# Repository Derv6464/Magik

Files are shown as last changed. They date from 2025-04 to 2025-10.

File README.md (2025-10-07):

# Magik - Flight Computer

This was built as a final year project for college, as well as to create a flight computer for ULAS HiPR.
The code and pcb are rough drafts with work to be done before the first flight. 

## Hardware
The code & pcb were created with a rp2040 chip in mind

## Report
Full report can be veiwed in the repo

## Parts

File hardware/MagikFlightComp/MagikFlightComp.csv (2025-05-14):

Comment | Designator | Footprint | LCSC
Antenna | AE1
Antenna | AE2 | Connector_Coaxial:SMA_Molex_73251-1153_EdgeMount_Horizontal
Buzzer | BZ1 | Buzzer_Beeper:Buzzer_12x9.5RM7.6
100nF | C1,C2,C3,C4,C6 | Capacitor_SMD:C_0603_1608Metric_Pad1.08x0.95mm_HandSolder
1uF | C10,C11 | Capacitor_SMD:C_0603_1608Metric_Pad1.08x0.95mm_HandSolder
10uF | C5 | Capacitor_SMD:C_0603_1608Metric_Pad1.08x0.95mm_HandSolder
47pF | C7 | Capacitor_SMD:C_0603_1608Metric_Pad1.08x0.95mm_HandSolder
22uF | C8,C9 | Capacitor_SMD:C_0603_1608Metric_Pad1.08x0.95mm_HandSolder
LED | D1 | LED_SMD:LED_1210_3225Metric
WS2812B | D2 | LED_SMD:LED_WS2812B_PLCC4_5.0x5.0mm_P3.2mm
2601-1104 | J1,J3 | CONN4_2601-1104_WAG
Debug Socket | J2
Conn_01x03_Socket | J4 | Connector_JST:JST_PH_B3B-PH-K_1x03_P2.00mm_Vertical
Conn_01x02_Pin | J5 | Connector_PinHeader_1.00mm:PinHeader_1x02_P1.00mm_Vertical
6.8uH | L1 | Inductor_SMD:L_0603_1608Metric_Pad1.05x0.95mm_HandSolder
NDT3055L | Q1,Q2 | Package_TO_SOT_SMD:SOT-223-3_TabPin2
1k | R1 | Resistor_SMD:R_0603_1608Metric_Pad0.98x0.95mm_HandSolder
10k | R2,R3 | Resistor_SMD:R_0603_1608Metric_Pad0.98x0.95mm_HandSolder
158k | R4 | Resistor_SMD:R_0603_1608Metric_Pad0.98x0.95mm_HandSolder
30.1k | R5 | Resistor_SMD:R_0603_1608Metric_Pad0.98x0.95mm_HandSolder
Pico | U1 | Module_RaspberryPi_Pico:RaspberryPi_Pico_W_SMD_HandSolder
Ai-Thinker-Ra-01 | U2 | RF_Module:Ai-Thinker-Ra-01-LoRa
MAX-M10S | U3 | RF_GPS:ublox_MAX
ADXL375BCCZ-RL7 | U4 | LGA_CC-14-1_ADI
LSM6DSO32TR | U5 | LSM6D032:LGA-14L_2P5X3X0P83_STM
MS560702BA03-50 | U6 | MS5607:SON8_MS5611_TEC
AP63300WU-7 | U7 | TSOT6_AP63300WU-7_DIO

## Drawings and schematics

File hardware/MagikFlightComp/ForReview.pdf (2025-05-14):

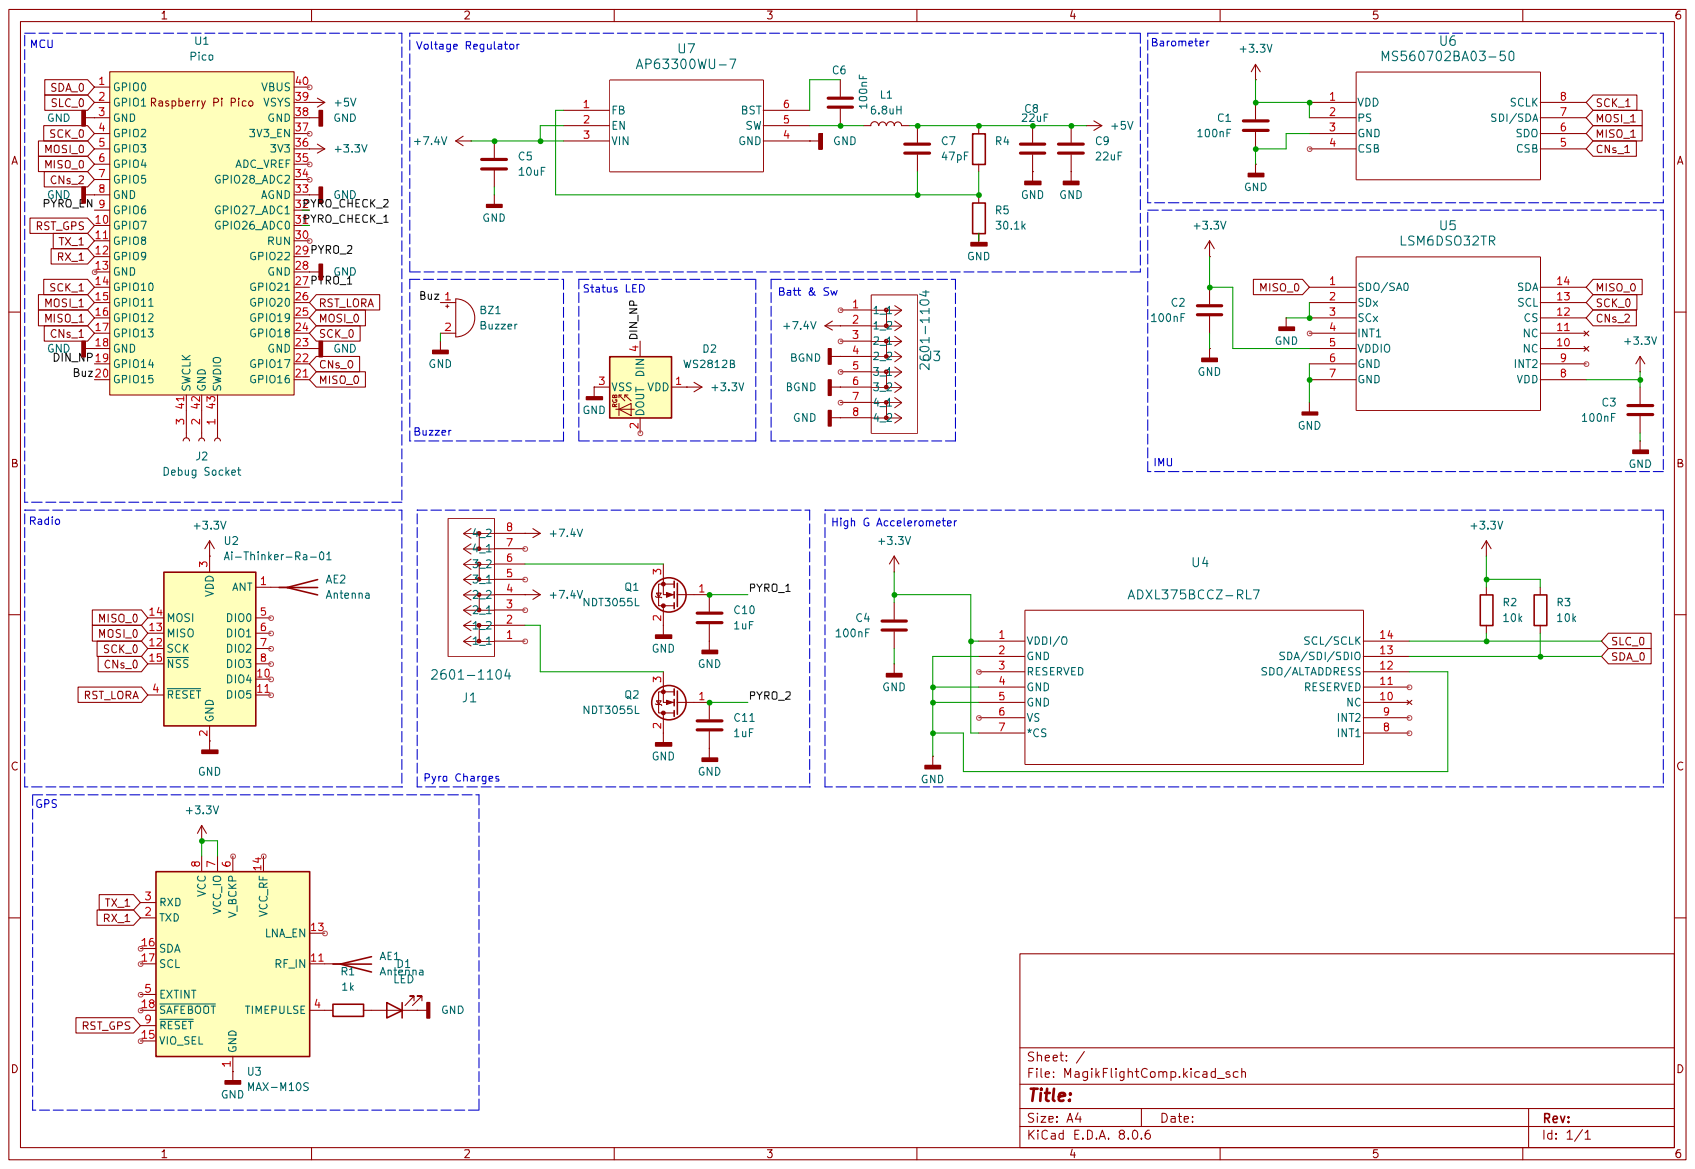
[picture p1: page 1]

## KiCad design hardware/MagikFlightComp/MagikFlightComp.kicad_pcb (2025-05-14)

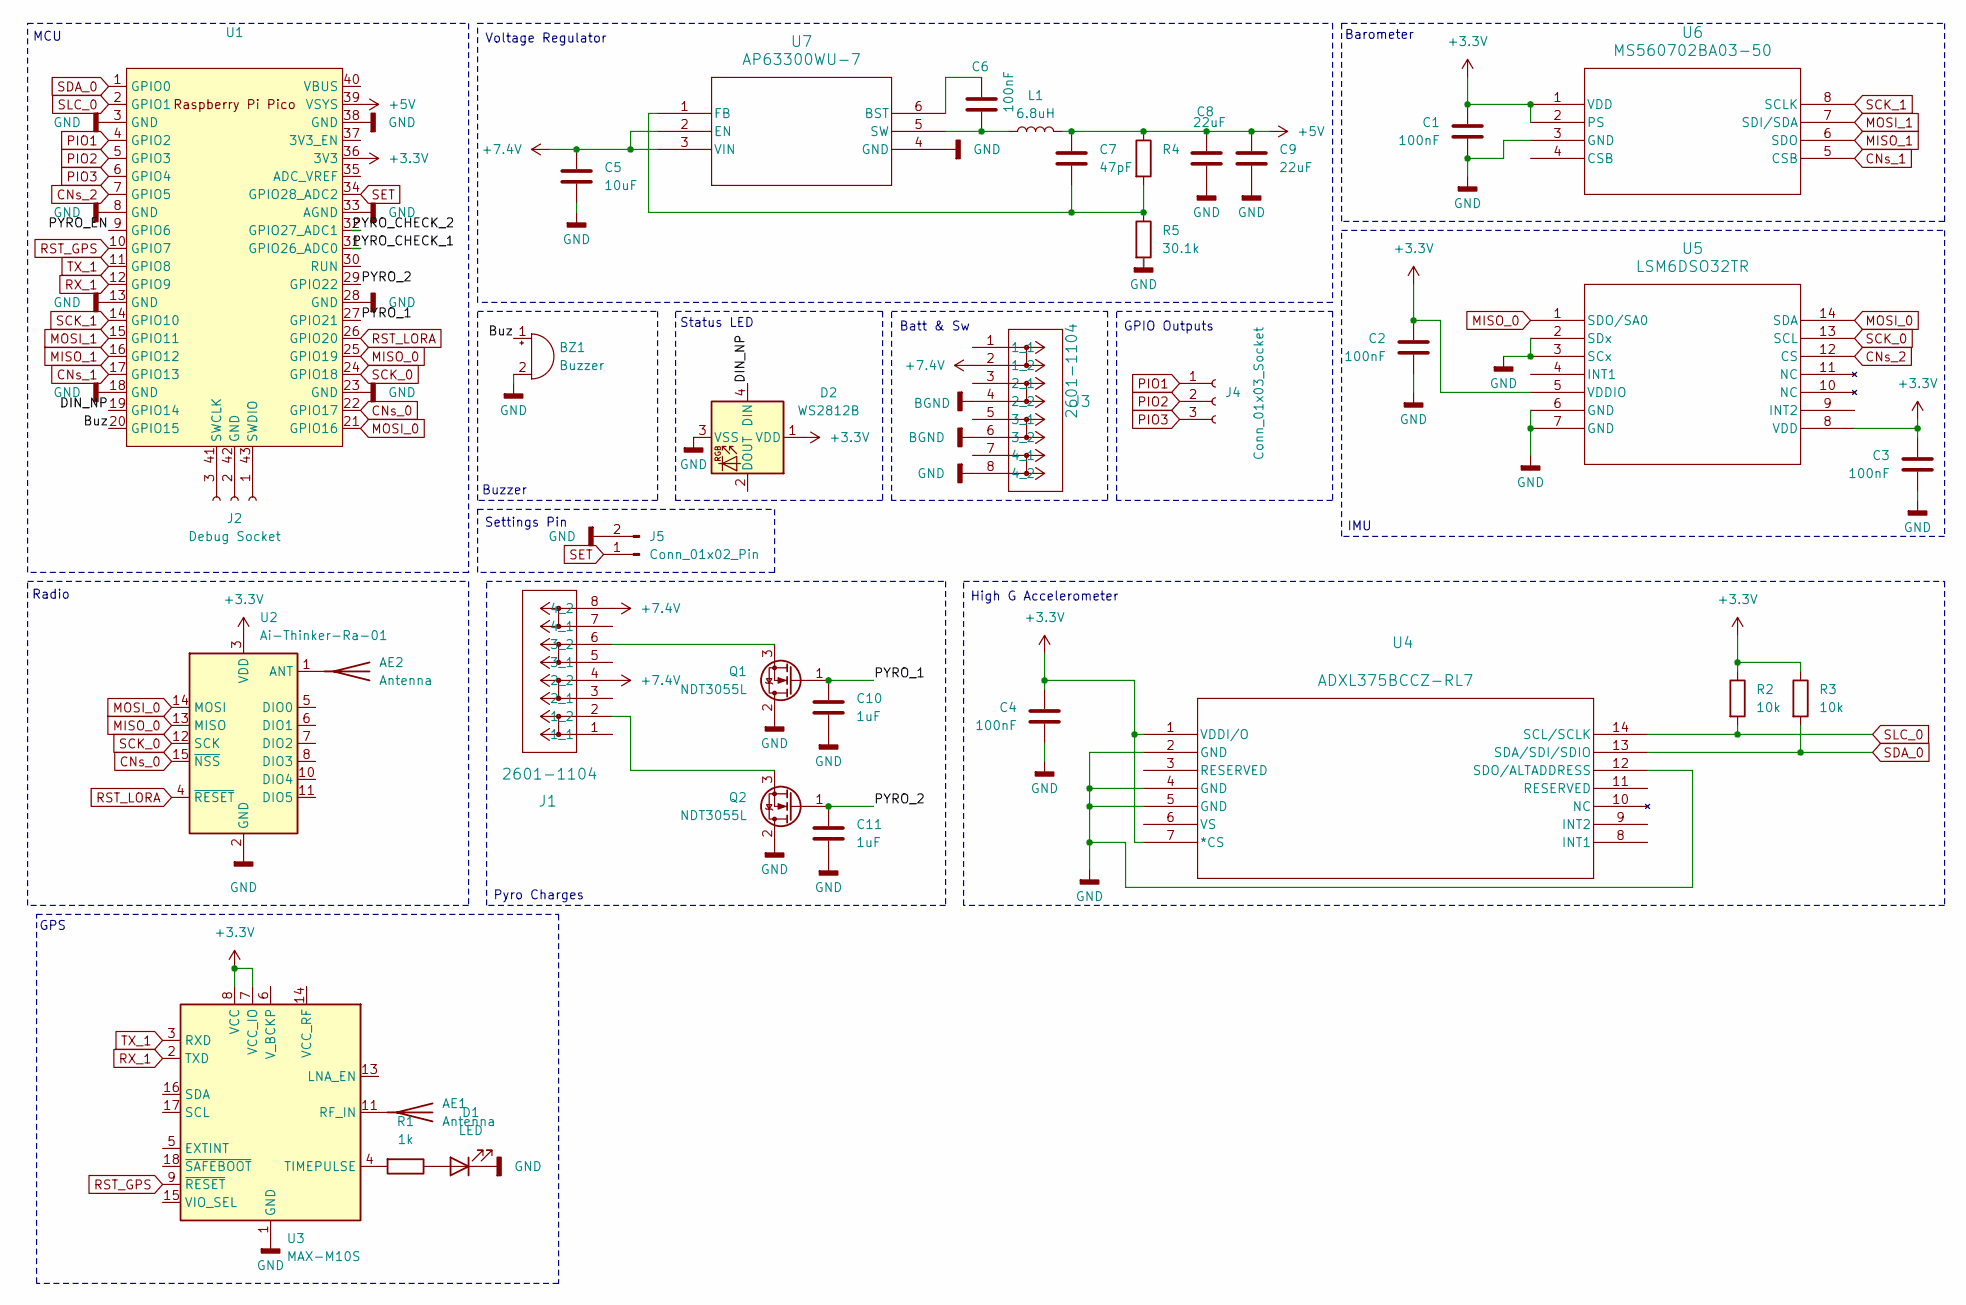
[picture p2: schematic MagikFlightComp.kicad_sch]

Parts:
AE1: Antenna
AE2: Antenna; SMA_Molex_73251-1153_EdgeMount_Horizontal
BZ1: Buzzer; Buzzer_12x9.5RM7.6
C1, C2, C3, C4, C6: 100nF; C_0603_1608Metric_Pad1.08x0.95mm_HandSolder
C5: 10uF; C_0603_1608Metric_Pad1.08x0.95mm_HandSolder
C7: 47pF; C_0603_1608Metric_Pad1.08x0.95mm_HandSolder
C8, C9: 22uF; C_0603_1608Metric_Pad1.08x0.95mm_HandSolder
C10, C11: 1uF; C_0603_1608Metric_Pad1.08x0.95mm_HandSolder
D1: LED; LED_1210_3225Metric
D2: WS2812B; LED_WS2812B_PLCC4_5.0x5.0mm_P3.2mm
J1, J3: 2601-1104; CONN4_2601-1104_WAG
J2: Debug Socket
J4: Conn_01x03_Socket; JST_PH_B3B-PH-K_1x03_P2.00mm_Vertical
J5: Conn_01x02_Pin; PinHeader_1x02_P1.00mm_Vertical
L1: 6.8uH; L_0603_1608Metric_Pad1.05x0.95mm_HandSolder
Q1, Q2: NDT3055L; SOT-223-3_TabPin2
R1: 1k; R_0603_1608Metric_Pad0.98x0.95mm_HandSolder
R2, R3: 10k; R_0603_1608Metric_Pad0.98x0.95mm_HandSolder
R4: 158k; R_0603_1608Metric_Pad0.98x0.95mm_HandSolder
R5: 30.1k; R_0603_1608Metric_Pad0.98x0.95mm_HandSolder
U1: Pico; RaspberryPi_Pico_W_SMD_HandSolder
U2: Ai-Thinker-Ra-01; Ai-Thinker-Ra-01-LoRa
U3: MAX-M10S; ublox_MAX
U4: ADXL375BCCZ-RL7; LGA_CC-14-1_ADI
U5: LSM6DSO32TR; LGA-14L_2P5X3X0P83_STM
U6: MS560702BA03-50; SON8_MS5611_TEC
U7: AP63300WU-7; TSOT6_AP63300WU-7_DIO

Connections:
+3.3V: C1.1, C2.1, C3.1, C4.1, D2.1 (VDD), R2.1, R3.1, U1.36 (3V3), U2.3 (VDD), U3.7 (VCC_IO), U3.8 (VCC), U4.1 (VDDI/O), U4.7 (*CS), U5.5 (VDDIO), U5.8 (VDD), U6.1 (VDD), U6.2 (PS)
+5V: C7.1, C8.1, C9.1, L1.2, R4.1, U1.39 (VSYS)
+7.4V: C5.1, J1.4 (2_2), J1.8 (4_2), J3.2 (1_2), U7.2 (EN), U7.3 (VIN)
/Buz: BZ1.1 (+), U1.20 (GPIO15)
/DIN_NP: D2.4 (DIN), U1.19 (GPIO14)
/PYRO_1: C10.1, Q1.1 (G), U1.27 (GPIO21)
/PYRO_2: C11.1, Q2.1 (G), U1.29 (GPIO22)
/PYRO_CHECK_1: U1.31 (GPIO26_ADC0)
/PYRO_CHECK_2: U1.32 (GPIO27_ADC1)
/PYRO_EN: U1.9 (GPIO6)
BGND: J3.4 (2_2), J3.6 (3_2)
CNs_0: U1.22 (GPIO17), U2.15 (~NSS)
CNs_1: U1.17 (GPIO13), U6.5 (CSB)
CNs_2: U1.7 (GPIO5), U5.12 (CS)
GND: BZ1.2 (-), C1.2, C2.2, C3.2, C4.2, C5.2, C8.2, C9.2, C10.2, C11.2, D1.1 (K), D2.3 (VSS), J3.8 (4_2), J5.2, Q1.2 (D), Q2.2 (D), R5.2, U1.3 (GND), U1.8 (GND), U1.13 (GND), U1.18 (GND), U1.23 (GND), U1.28 (GND), U1.33 (AGND), U1.38 (GND), U2.2 (GND), U2.9 (GND), U2.16 (GND), U3.1 (GND), U3.10 (GND), U3.12 (GND), U4.2 (GND), U4.4 (GND), U4.5 (GND), U4.12 (SDO/ALTADDRESS), U5.2 (SDx), U5.3 (SCx), U5.6 (GND), U5.7 (GND), U6.3 (GND), U7.4 (GND)
MISO_0: U1.25 (GPIO19), U2.13 (MISO), U5.1 (SDO/SA0)
MISO_1: U1.16 (GPIO12), U6.6 (SDO)
MOSI_0: U1.21 (GPIO16), U2.14 (MOSI), U5.14 (SDA)
MOSI_1: U1.15 (GPIO11), U6.7 (SDI/SDA)
unnamed: AE1.1, U3.11 (RF_IN)
unnamed: AE2.1 (A), U2.1 (ANT)
unnamed: D1.2 (A), R1.1
unnamed: J1.2 (1_2), Q2.3 (S)
unnamed: J1.6 (3_2), Q1.3 (S)
unnamed: J2.1, U1.43 (SWDIO)
unnamed: J2.2, U1.42 (GND)
unnamed: J2.3, U1.41 (SWCLK)
unnamed: R1.2, U3.4 (TIMEPULSE)
unnamed: C6.1, U7.6 (BST)
unnamed: C7.2, R4.2, R5.1, U7.1 (FB)
unnamed: C6.2, L1.1, U7.5 (SW)
PIO1: J4.1, U1.4 (GPIO2)
PIO2: J4.2, U1.5 (GPIO3)
PIO3: J4.3, U1.6 (GPIO4)
RST_GPS: U1.10 (GPIO7), U3.9 (~RESET)
RST_LORA: U1.26 (GPIO20), U2.4 (~RESET)
RX_1: U1.12 (GPIO9), U3.2 (TXD)
SCK_0: U1.24 (GPIO18), U2.12 (SCK), U5.13 (SCL)
SCK_1: U1.14 (GPIO10), U6.8 (SCLK)
SDA_0: R3.2, U1.1 (GPIO0), U4.13 (SDA/SDI/SDIO)
SET: J5.1, U1.34 (GPIO28_ADC2)
SLC_0: R2.2, U1.2 (GPIO1), U4.14 (SCL/SCLK)
TX_1: U1.11 (GPIO8), U3.3 (RXD)

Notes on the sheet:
Radio
Buzzer
Settings Pin
High G Accelerometer
Voltage Regulator
GPS
MCU
Status LED
IMU
Batt & Sw
GPIO Outputs
Pyro Charges
Barometer

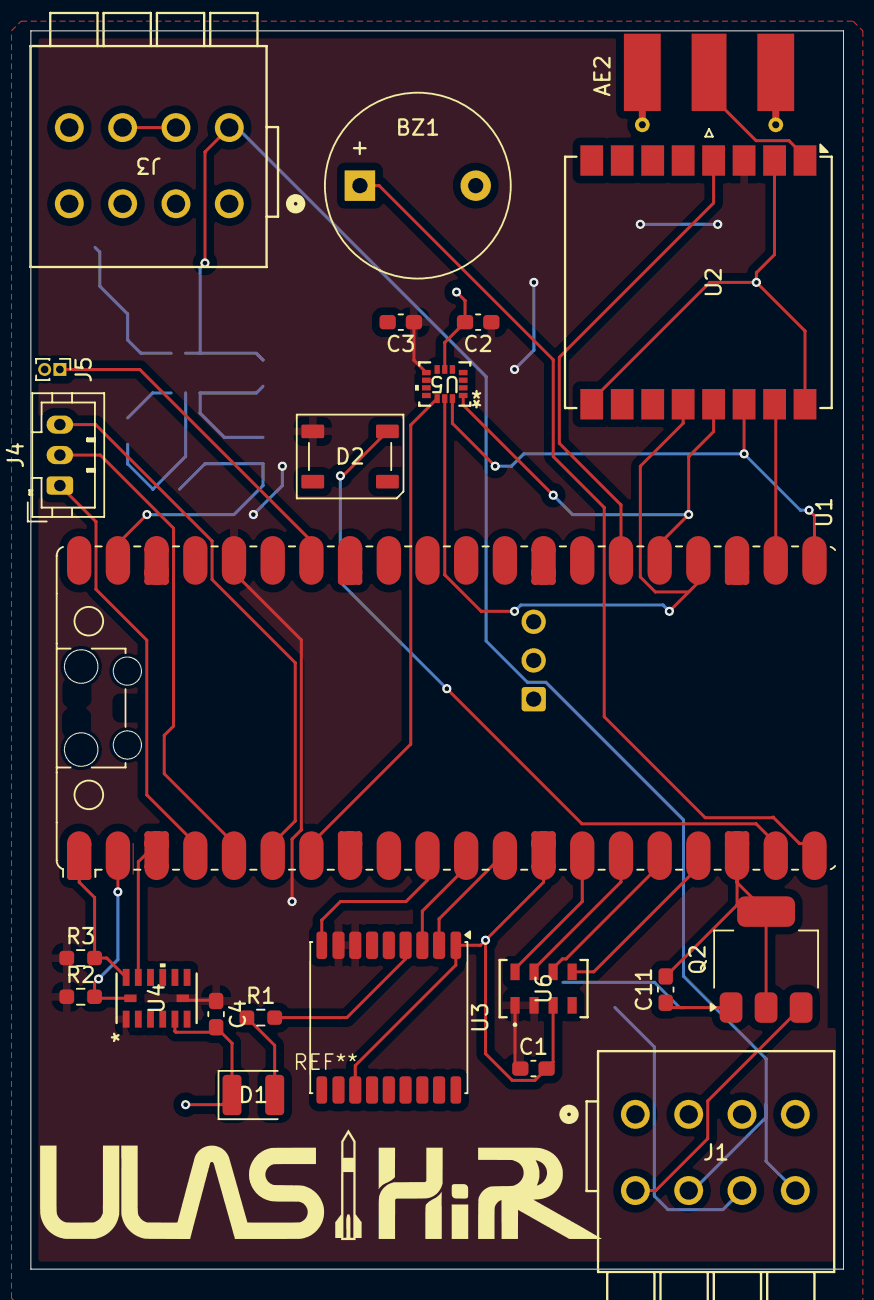
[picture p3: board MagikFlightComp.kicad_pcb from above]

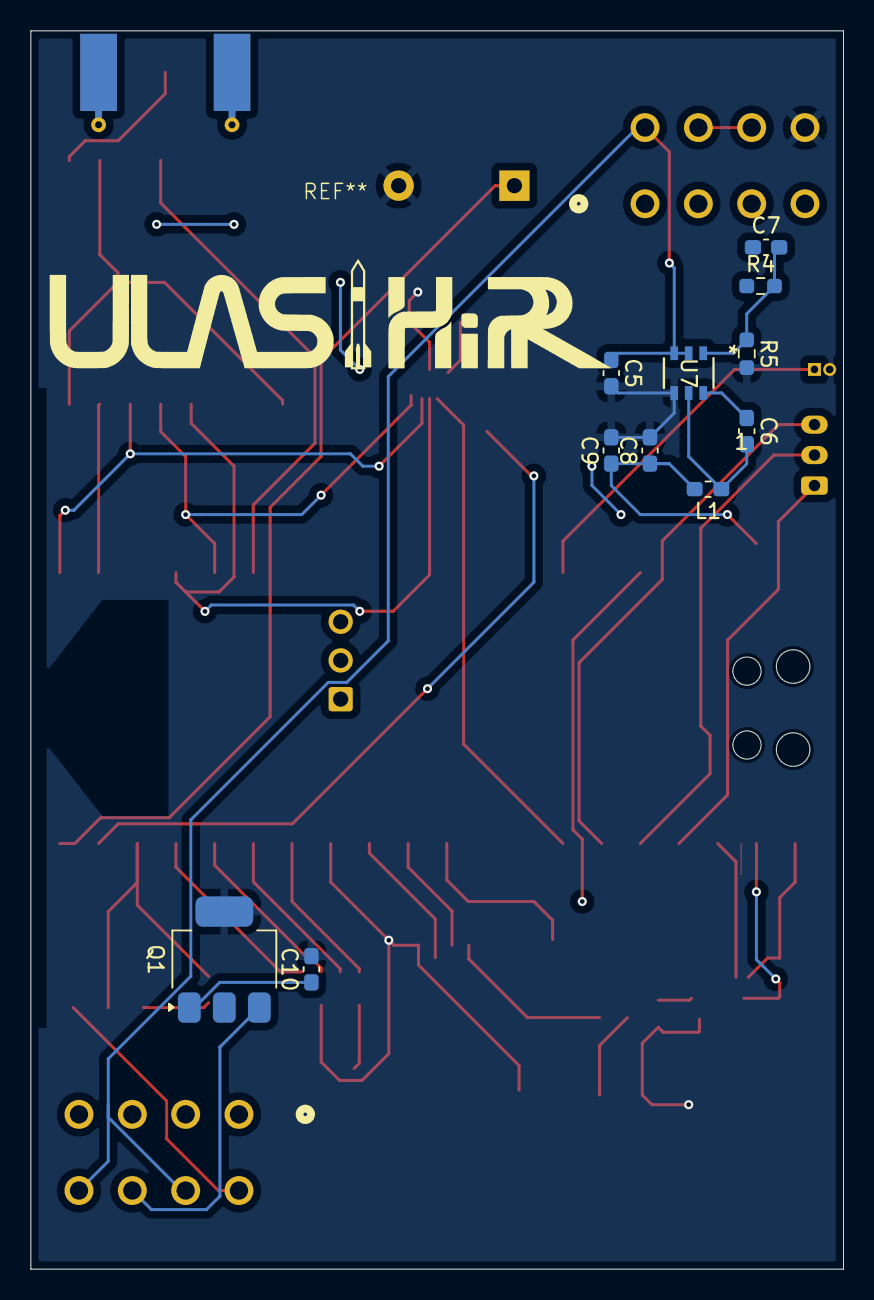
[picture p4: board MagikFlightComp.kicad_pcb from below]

Board: 2 copper layers, 53.3 x 81.3 mm, 34 parts (11 on the bottom side), 36 nets.

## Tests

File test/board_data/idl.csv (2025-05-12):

ts | ts | height | velocity | acceleration | FHeight | FAccel | eggAlt | eggFAlt | eggVel | LDA | Apogee | N-O | Drogue | Main | upper_alt_vega | lower_alt_vega | upper_alt_egg | lower_alt_egg | upper_alt_vega_percent | lower_alt_vega_percent | upper_alt_egg_percent | lower_alt_egg_percent | time | alt | vel | acc | state | time_scaled
0 | -0.75 | 0.4530242681503296 | 0.1455255150794983 | -0.0207533612847328 | 0.8725128173828125 | 0.0097312927246093 |  |  |  |  |  |  |  |  | 100.45302426815033 | -99.54697573184967 |  |  | 0.4983266949653626 | 0.40772184133529665 |  |  | 0.0 | -30.28533 | 24.785067 | 0.489704 | 1.0 | -0.75
1 | -0.74 | 0.4542248249053955 | 0.1450555771589279 | -0.0207574479281902 | 0.4420928955078125 | 0.0097312927246093 |  |  |  |  |  |  |  |  | 100.4542248249054 | -99.5457751750946 |  |  | 0.4996473073959351 | 0.40880234241485597 |  |  | 0.161 | -14.82827 | 27.38938 | 0.489754 | 1.0 | -0.7339
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

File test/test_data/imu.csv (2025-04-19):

ts | Ax | Ay | Az
-0.755 | -0.037109375 | -0.48974609375 | -0.08544921875
-0.745 | -0.0361328125 | -0.4931640625 | -0.07861328125
-0.735 | -0.0361328125 | -0.4931640625 | -0.07861328125
-0.725 | -0.037109375 | -0.498046875 | -0.07958984375
-0.715 | -0.0390625 | -0.4970703125 | -0.0859375
-0.705 | -0.03662109375 | -0.49560546875 | -0.07958984375
-0.695 | -0.0400390625 | -0.494140625 | -0.07861328125
-0.685 | -0.03955078125 | -0.4921875 | -0.0849609375
-0.675 | -0.03955078125 | -0.49072265625 | -0.080078125
-0.665 | -0.041015625 | -0.49169921875 | -0.08154296875
-0.655 | -0.03955078125 | -0.4951171875 | -0.0849609375
-0.645 | -0.0419921875 | -0.4951171875 | -0.078125
-0.635 | -0.03515625 | -0.49462890625 | -0.08447265625
-0.625 | -0.041015625 | -0.49609375 | -0.07861328125
-0.615 | -0.03515625 | -0.49169921875 | -0.0791015625
-0.605 | -0.03662109375 | -0.4912109375 | -0.07763671875
-0.595 | -0.04052734375 | -0.49169921875 | -0.0791015625
-0.585 | -0.03369140625 | -0.4912109375 | -0.08056640625
-0.575 | -0.04248046875 | -0.4951171875 | -0.08203125
-0.565 | -0.03759765625 | -0.49609375 | -0.0869140625
-0.555 | -0.0400390625 | -0.49609375 | -0.08349609375
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

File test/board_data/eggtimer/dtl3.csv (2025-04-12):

T | Alt | FAlt | FVeloc | LDA | Apogee | N-O | Drogue | Main | AUX
0.00 | 10.00 | 2.00 | 40.00 | 0 | 0 | 0 | 0 | 0 | 0
0.05 | 18.00 | 5.20 | 64.00 | 0 | 0 | 0 | 0 | 0 | 0
0.10 | 17.00 | 7.56 | 47.20 | 0 | 0 | 0 | 0 | 0 | 0
0.15 | 25.00 | 11.05 | 69.76 | 0 | 0 | 0 | 0 | 0 | 0
0.20 | 32.00 | 15.24 | 83.81 | 0 | 0 | 0 | 0 | 0 | 0
0.25 | 39.00 | 19.99 | 95.05 | 0 | 0 | 0 | 0 | 0 | 0
0.30 | 53.00 | 26.59 | 132.04 | 0 | 0 | 0 | 0 | 0 | 0
0.35 | 66.00 | 34.47 | 157.63 | 0 | 0 | 0 | 0 | 0 | 0
0.40 | 82.00 | 43.98 | 190.10 | 0 | 0 | 0 | 0 | 0 | 0
0.45 | 100.00 | 55.18 | 224.08 | 0 | 0 | 0 | 0 | 0 | 0
0.50 | 117.00 | 67.55 | 247.27 | 0 | 0 | 0 | 0 | 0 | 0
0.55 | 122.00 | 78.44 | 217.81 | 0 | 0 | 0 | 0 | 0 | 0
0.60 | 136.00 | 89.95 | 230.25 | 0 | 0 | 0 | 0 | 0 | 0
0.65 | 157.00 | 103.36 | 268.20 | 0 | 0 | 0 | 0 | 0 | 0
0.70 | 176.00 | 117.89 | 290.56 | 0 | 0 | 0 | 0 | 0 | 0
0.75 | 218.00 | 137.91 | 400.45 | 218 | 0 | 0 | 0 | 0 | 0
0.80 | 237.00 | 157.73 | 396.36 | 0 | 0 | 0 | 0 | 0 | 0
0.85 | 251.00 | 176.38 | 373.09 | 0 | 0 | 0 | 0 | 0 | 0
0.90 | 268.00 | 194.71 | 366.47 | 0 | 0 | 0 | 0 | 0 | 0
0.95 | 276.00 | 210.96 | 325.18 | 0 | 0 | 0 | 0 | 0 | 0
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

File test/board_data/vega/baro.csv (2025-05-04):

ts | id | T | P
-0.755 | BARO0 | 41.18 | 99694
-0.745 | BARO0 | 41.19 | 99696
-0.735 | BARO0 | 41.19 | 99688
-0.725 | BARO0 | 41.19 | 99704
-0.715 | BARO0 | 41.17 | 99679
-0.705 | BARO0 | 41.2 | 99693
-0.695 | BARO0 | 41.18 | 99678
-0.685 | BARO0 | 41.19 | 99674
-0.675 | BARO0 | 41.2 | 99703
-0.665 | BARO0 | 41.19 | 99707
-0.655 | BARO0 | 41.17 | 99685
-0.645 | BARO0 | 41.19 | 99683
-0.635 | BARO0 | 41.19 | 99693
-0.625 | BARO0 | 41.19 | 99687
-0.615 | BARO0 | 41.19 | 99702
-0.605 | BARO0 | 41.21 | 99685
-0.595 | BARO0 | 41.19 | 99685
-0.585 | BARO0 | 41.19 | 99681
-0.575 | BARO0 | 41.19 | 99707
-0.565 | BARO0 | 41.21 | 99681
-0.555 | BARO0 | 41.19 | 99695
-0.545 | BARO0 | 41.19 | 99701
-0.535 | BARO0 | 41.18 | 99698
-0.525 | BARO0 | 41.19 | 99673
-0.515 | BARO0 | 41.18 | 99674
-0.505 | BARO0 | 41.19 | 99706
-0.495 | BARO0 | 41.22 | 99707
-0.485 | BARO0 | 41.18 | 99684
-0.475 | BARO0 | 41.2 | 99692
-0.465 | BARO0 | 41.18 | 99701
-0.455 | BARO0 | 41.19 | 99705
-0.445 | BARO0 | 41.19 | 99698
-0.435 | BARO0 | 41.18 | 99701
-0.425 | BARO0 | 41.18 | 99679
-0.415 | BARO0 | 41.17 | 99701
-0.405 | BARO0 | 41.2 | 99703
-0.395 | BARO0 | 41.21 | 99702
-0.385 | BARO0 | 41.18 | 99680
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

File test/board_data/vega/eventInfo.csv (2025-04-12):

ts | event | action | argument
0 | 2 | 7 | 2
5.69 | 3 | 0 | 0
21.221 | 4 | 1 | 1000
22.221 | 4 | 2 | 1
22.221 | 4 | 1 | 2000
24.221 | 4 | 2 | 0
110.36 | 5 | 3 | 1
110.36 | 5 | 1 | 2000
112.36 | 5 | 3 | 0

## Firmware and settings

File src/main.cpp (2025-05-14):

#include "FreeRTOS.h"
#include "task.h"
#include <stdio.h>
#include "pico/stdlib.h"
#ifdef CYW43_WL_GPIO_LED_PIN
#include "pico/cyw43_arch.h"
#endif
#include <hardware/flash.h>

#include "btstack.h"
#include "pico/cyw43_arch.h"
#include "pico/btstack_cyw43.h"

#include "tools/bt_server_gap.h"
#include "tools/bt_server_gatt.h"
#include "tools/state_machine.h"
#include "tools/interfaces.h"
#include "tools/settings.h"

#include "sensors/barometer.h"
#include "sensors/accelerometer.h"
#include "sensors/gps.h"
#include "sensors/sensor_handler.h"
#include "sensors/data.h"

#include "config.h"

#include "outputs/status_led.h"
#include "outputs/radio.h"
#include "outputs/logger.h"
#include "outputs/telemetry.h"
#include "outputs/pyro.h"

#ifdef TESTING
#include "drivers/test_input/test_handler.h"
#endif

#include <Eigen/Dense>
 
using Eigen::MatrixXd;


void handle_calibrating() { 
    printf("State: CALIBRATING\n"); 
}
void handle_ready() { printf("State: READY\nAll sensors good\n"); }
void handle_powered(Pyro* ignite) { 
    printf("State: POWERED\n");
    printf("unlcking pyro\n");
    ignite->unlock();
 }
void handle_coasting() { printf("State: COASTING\n"); }
void handle_drouge(int delay, Pyro* ignite) { 
    sleep_ms(delay);
    ignite->fire(1);
    printf("State: DROUGE\n");
 }
void handle_main(Pyro* ignite) { 
    ignite->fire(2);
    printf("State: MAIN\n");
}

void handle_landed(TaskHandle_t secHandle, TaskHandle_t telemHandle) { 
    printf("State: LANDED\n");
    vTaskPrioritySet(secHandle, 5);
    //vTaskPrioritySet(telemHandle, 5);
 }

struct StateMachineArgs {
    StateMachine* fsm;
    AllQueuesArgs* queues; 
};

struct TelemetryArgs{
    Telemetry* telem;
    QueueHandle_t flightDataQueue;
};

static void run_task(void* pvParameters) {
    printf("State Machine Task\n");
    StateMachineArgs* args = static_cast<StateMachineArgs*>(pvParameters);
    args->fsm->run(args->queues);
};

static void run_telem(void* pvParameters) {
    printf("State Machine Task\n");
    TelemetryArgs* args = static_cast<TelemetryArgs*>(pvParameters);
    args->telem->run(args->flightDataQueue);
};

void run_core_sensors(void* pvParameters) {
    printf("Core Sensor Task\n");
    SensorHandler<core_flight_data>* handler = static_cast<SensorHandler<core_flight_data>*>(pvParameters);
    core_flight_data data;
    data.time = to_ms_since_boot(get_absolute_time());
    handler->runSensors(&data); 
};

void run_secondary_sensors(void* pvParameters) {
    printf("Secondary Sensor Task\n");
    SensorHandler<secondary_flight_data>* handler = static_cast<SensorHandler<secondary_flight_data>*>(pvParameters);
    secondary_flight_data data;
    handler->runSensors(&data); 
};


#ifdef TESTING
void run_test_hander(void* pvParameters) {
    TestHandler* handler = static_cast<TestHandler*>(pvParameters);
    while (true) {
        handler->split_data();
        vTaskDelay(pdMS_TO_TICKS(read_data_delay));
    }
};
#endif

void run_flight(Status_led* status_led, FlightSettings* flight_settings) {
    QueueHandle_t coreDataQueue = xQueueCreate(3, sizeof(core_flight_data));
    QueueHandle_t secDataQueue = xQueueCreate(3, sizeof(secondary_flight_data));
    QueueHandle_t flightDataQueue = xQueueCreate(1, sizeof(flight_data));

    printf("Starting...\n");
    printf("flightDataQueue: %d\n", sizeof(flight_data));
    printf("coreDataQueue: %d\n", sizeof(core_flight_data));
    printf("secDataQueue: %d\n", sizeof(secondary_flight_data));

    Pyro* ignite = new Pyro(pyro_1, pyro_2, pyro_en);
    ignite->lock();

    uart_inst_t* port = uart_get_instance(1);
    i2c_inst_t* i2c_port = i2c_get_instance(0);

    #ifdef TESTING
    UART uart_1(tx_1, rx_1, port, 115200, 11);
    TestHandler testHandler(&uart_1);
  
    Barometer barometer(&testHandler); 
    Accelerometer accelerometer(&testHandler);
    GPS gps(&testHandler);
    Radio* radio = new Radio();
    Logger* logger = new Logger();
    #else
    SPI spi_1(sck_1, mosi_1, miso_1, spi1);
    Barometer barometer(&spi_1, cs_baro);

    //I2C i2c_0(sda_0, scl_0, i2c_port);
    PIO pio = pio0;
    I2C_PIO i2c_0(sck_0, mosi_0, pio);
    int mpu = 0x68;
    Accelerometer accelerometer(&i2c_0, mpu);
    core_flight_data coreData;
    accelerometer.update(&coreData);
    //printf("Accelerometer: %f %f %f\n", coreData.acceleration.x, coreData.acceleration.y, coreData.acceleration.z);
    #endif

    TaskHandle_t telemHandel; 
    TaskHandle_t secHandel;


    printf("UART created\n");
    
    SensorHandler<core_flight_data> core_sensors(coreDataQueue);
    core_sensors.addSensor(&barometer);
    core_sensors.addSensor(&accelerometer);

    SensorHandler<secondary_flight_data> sec_sensors(secDataQueue);
    //sec_sensors.addSensor(&gps);

    StateMachine::StateHandler state_handlers[] = {
        handle_calibrating,
        handle_ready,
        [=]() { handle_powered(ignite); },
        handle_coasting,
        [=]() { handle_drouge(flight_settings->getDrougeDeployDelay(), ignite); },
        [=]() { handle_main(ignite); },
        [=]() { handle_landed(secHandel, telemHandel); },
    };

    StateMachine* fsm = new StateMachine(state_handlers, flight_settings->get_settings());
    //take in flight settings to init heights

    StateMachineArgs* fsmArgs = new StateMachineArgs{
        .fsm = fsm,
        .queues = new AllQueuesArgs{
            .coreDataQueue = coreDataQueue,
            .secDataQueue = secDataQueue,
            .flightDataQueue = flightDataQueue
        }
    };

    //Telemetry* telemetry = new Telemetry(radio, logger);
//
    //TelemetryArgs* telemArgs = new TelemetryArgs{
    //    .telem = telemetry,
    //    .flightDataQueue = flightDataQueue
    //};
    status_led->set_color(Status_led::Color::GREEN);

    xTaskCreate(run_task, "Flight_State_Task", 512, fsmArgs, 3, NULL);
    xTaskCreate(run_core_sensors, "CoreSensorTask", 512, &core_sensors, 4, NULL);
    xTaskCreate(run_secondary_sensors, "SecondarySensorTask", 256, &sec_sensors, 2, &secHandel);
    #ifdef TESTING
    xTaskCreate(run_test_hander, "TestHandlerTask", 512, &testHandler, 5, NULL);
    #endif
    //xTaskCreate(printRunning, "PrintTask", 256, NULL, 3, NULL);
    //xTaskCreate(run_telem, "Telemetry Task", 512, telemArgs, 2, &telemHandel);

    vTaskStartScheduler();

    while (1) {
        //never reach here
    };
}

#define HEARTBEAT_PERIOD_MS 250

// BTstack objects
static btstack_timer_source_t heartbeat;
static btstack_packet_callback_registration_t hci_event_callback_registration;
static int characteristic_appogee_value = 0;

static char characteristic_apogee_value_tx[10];
static char characteristic_apogee_value_rx[10];
static char characteristic_main_value_tx[10];
static char characteristic_main_value_rx[10];
static char characteristic_done_value_rx[10];


int run_settings(Status_led* status_led, FlightSettings* flight_settings) {
    printf("Settings\n");
    status_led->set_color(Status_led::Color::BLUE);
     // initialize CYW43 driver architecture (will enable BT if/because CYW43_ENABLE_BLUETOOTH == 1)
     if (cyw43_arch_init()) {
        printf("failed to initialise cyw43_arch\n");
        return -1;
    }

    // Initialize L2CAP and security manager
    l2cap_init();
    sm_init();

    // Initialize ATT server, no general read/write callbacks
    // because we'll set one up for each service
    att_server_init(profile_data, NULL, NULL);   

    // Instantiate our custom service handler
    service_handler = custom_service_server_init( 
        characteristic_apogee_value_tx,
        characteristic_main_value_tx,
        characteristic_apogee_value_rx,
        characteristic_main_value_rx,
        characteristic_done_value_rx
    ); ;

    att_server_register_service_handler(&service_handler);
    printf("Registered service handler: start=0x%04x, end=0x%04x\n", service_handler.start_handle, service_handler.end_handle);
    printf("Registered service handler: start=0x%04x, end=0x%04x\n", service_handler.write_callback, service_handler.read_callback);

    // inform about BTstack state
    hci_event_callback_registration.callback = &packet_handler;
    hci_add_event_handler(&hci_event_callback_registration);

    // register for ATT event
    att_server_register_packet_handler(packet_handler);

    // turn on bluetooth!
    hci_power_control(HCI_POWER_ON);
    
    //if recveice notifiy
    //if (strcmp(characteristic_done_value_rx, "done") == 0) {
    //    printf("Received done\n");
    flash_internal_data settings = {
        .main_height = 1,
        .drouge_delay = 1,
        .liftoff_thresh = 1,
        .last_log = 0
    };  

    flight_settings->save_settings(settings);


    #if 0 // btstack_run_loop_execute() is not required, so lets not use it
        btstack_run_loop_execute();
    #else
        // this core is free to do it's own stuff except when using 'polling' method (in which case you should use 
        // btstacK_run_loop_ methods to add work to the run loop.

        // this is a forever loop in place of where user code would go.
        while(true) {      
            //sleep_ms(1000);

            //printf("Running\n");
        }
    #endif
        return 0;
}

int main() {
    stdio_init_all();
    
    gpio_init(bt_setting_pin);
    gpio_set_dir(bt_setting_pin, GPIO_IN);
    gpio_pull_up(bt_setting_pin);

    Status_led status_led(neopixel);
    status_led.set_color(Status_led::Color::RED);
  
    FlightSettings flight_settings;
    //whats saved in flash rn:
    //flight_settings.save_settings({
    //    .main_height = 200,
    //    .drouge_delay = 0,
    //    .liftoff_thresh = 30,
    //    .last_log = 0
    //});
    flight_settings.read_settings();

    if (!gpio_get(bt_setting_pin)) {  
        printf("Running settings\n");
        run_settings(&status_led, &flight_settings);
    } else {
        printf("Running flight\n");
        run_flight(&status_led, &flight_settings);
    }
};

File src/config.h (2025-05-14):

#pragma once

//#define TESTING
#define TEST_RIG

#define read_data_delay 50 //ms 
#define send_data_delay 5000 //ms

//#define BARO_BMP390
//#define ACCEL_LSM6DS3
//#define ACCEL_ADXL345
#define ACCEL_MPU6050
//#define GPS_MAXM10S
//#define RADIO_SX1278
//#define LOG_SD

#ifdef TEST_RIG
#define BARO_BMP390
//#define ACCEL_LSM6DSOX
//#define GPS_PA
//#define RADIO_RM95W

#endif


#define LOG_INTERNAL_FLASH
#define LOG_FLASH_OFFSET 1024*1024 
#define SETTINGS_OFFSET 1024*512 

//I2C bus for high g accelerometer
//#define sda_0 0
//#define scl_0 1

//I2C bus for accelerometer
#define sda_0 4
#define scl_0 5

//SPI bus for barometer and low g accelerometer/IMU
#define sck_1 10
#define mosi_1 11
#define miso_1 12
#define cs_baro 13
#define cs_imu 5

//SPI bus for LoRa
#define sck_0 18
#define mosi_0 19
#define miso_0 16
#define cs_lora 17
#define rst_lora 20

#define neopixel 14
#define buzzer 15

//UART bus for GPS
//#define tx_1 8
//#define rx_1 9
#define rst_gps 7

#ifdef TESTING
//UART bus for testing
#define tx_1 8
#define rx_1 9

#endif

//Pyro channels
#define pyro_en 6
#define pyro_1 26
#define pyro_2 27
//#define pyro_check_1 26
//#define pyro_check_2 27

#define bt_setting_pin 2

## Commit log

2025-03-23 status led be working :)
2025-03-30 added sensor handling
2025-04-12 bunch of sensor and testing stuff
    [baro.csv, dtl3.csv, eventInfo.csv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]
2025-04-15 other files for testing pico
2025-04-17 why has git broken
    [accelerometer.cpp, barometer.cpp, bmp390.cpp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]
2025-04-19 fixing testing & state machine
    [imu.csv]
2025-04-21 velocity working, logging questionable
2025-04-22 drivers for mpu6050 with i2c, and very base bt server class
2025-04-26 kalman done kinda, velocity no work
2025-05-04 results r fucked
    [baro.csv, diff.csv, diff.txt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]
2025-05-07 bt server, and starting gps driver
2025-05-08 idk anymore p2
    [diff.csv, diff.txt, results.csv]
2025-05-12 final commit
    [idl.csv]
2025-05-14 added pcb files
    [MagikFlightComp.csv, MagikFlightComp.kicad_pcb, MagikFlightComp.kicad_sch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]
